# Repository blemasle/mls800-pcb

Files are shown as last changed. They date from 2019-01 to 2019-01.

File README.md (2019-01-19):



# MLS800 PCBs

MLS800 preview 1

The MLS800 is an open-source 1U rack unit MIDI controlled Loop Switcher with 8 audio loops.  

* 8 independent audio loops
* 128 presets
* Active preset is remotly controlled through MIDI `Program Change` messages
* Easy to read through a 4 digits 7 segments display and 9 illuminated switches

This repository contains KiCad files needed to produce the two PCBs.  

&nbsp;


See the [documentation](https://blemasle.github.io/mls800) for futher info on the project.

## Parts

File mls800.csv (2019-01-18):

References | Quantity | Manufacturer | Manufacturer PN
D2;D6 | 2 | Diodes Incorporated | S1A-13-F
CON1 | 1 | Switchcraft | RAPC722X
R14;R13 | 2 | Panasonic | ERJ-P06J220V
X1 | 1 | ECS Inc | ECS-160-20-5PX-TR
C1;C2 | 2 | Kemet | C0805C220K3GACTU
C6 | 1 | Kemet | C0805C105K3RACTU
F1 | 1 | Bourns | MF-MSMF050-2
C8 | 1 | Kemet | C1210C226K4RACTU
R4;R1;R6;R7 | 4 | Panasonic | ERJ-6GEYJ103V
C9;C5;C4;C7;C10;C11;C14;C18;C12;C20;C13 | 11 | Kemet | C0805C104M3RACTU
D1;D5 | 2 | Vishay | 1N4148W-E3-08
D3 | 1 | Kingbright | APT2012SYCK
R9;R10;R11;R12;R18;R8;R5 | 7 | Panasonic | ERJ-6GEYJ102V
D4 | 1 | Kingbright | APT2012EC
U3 | 1 | Microchip | 24LC256I/SN
R15;R17;R16 | 3 | Panasonic | ERJ-6GEYJ221V
IC1 | 1 | Fairchild Semiconductor | 6N137SM
C3;C17 | 2 | Kemet | C0805C224K3RACTU
P1;P4;P5 | 3 | FCI | 75869-131LF
VR2;VR1 | 2 | Bourns | CG0603MLC-05E
J1 | 1 | Molex Inc | 67068-8000
U1;U8 | 2 | Texas Instruments | LM340MP-5.0/NOPB
U2 | 1 | Atmel | ATMega32U4-AU
C15;C19;C16 | 3 | Panasonic | EEE-TPC101XAP
R2 | 1 | Panasonic | ERJ-6GEY0R00V
P2;P3 | 2 | TE Connectivity | 5212044-1
SW12 | 1 | Apem | MJTP1236C
U4 | 1 | Microchip | MCP23017-E/SS
RE1;RE2;RE3;RE4;RE5;RE6;RE7;RE8 | 8 | TE Connectivity | V23079E1201B301
J3;J4;J5;J6;J7;J8;J9;J10 | 8 | Neutrik | NSJ8HC
J2;J11 | 2 | Neutrik | NRJ4HF-1
U7;U6 | 2 | Texas Instruments | ULN2803ADW
AFF1 | 1 | Lite-On | LTC-5723HR
U5 | 1 | ams AG | AS1115-BSST
R19 | 1 | Panasonic | ERJ-6GEYJ243V
SW2;SW3;SW4;SW5;SW6;SW7;SW8;SW9;SW10;SW11 | 10 | Apem | 5GSH93582
SW2;SW3;SW4;SW5;SW6;SW7;SW8;SW9;SW10;SW11 | 10 | Apem | 1ES096

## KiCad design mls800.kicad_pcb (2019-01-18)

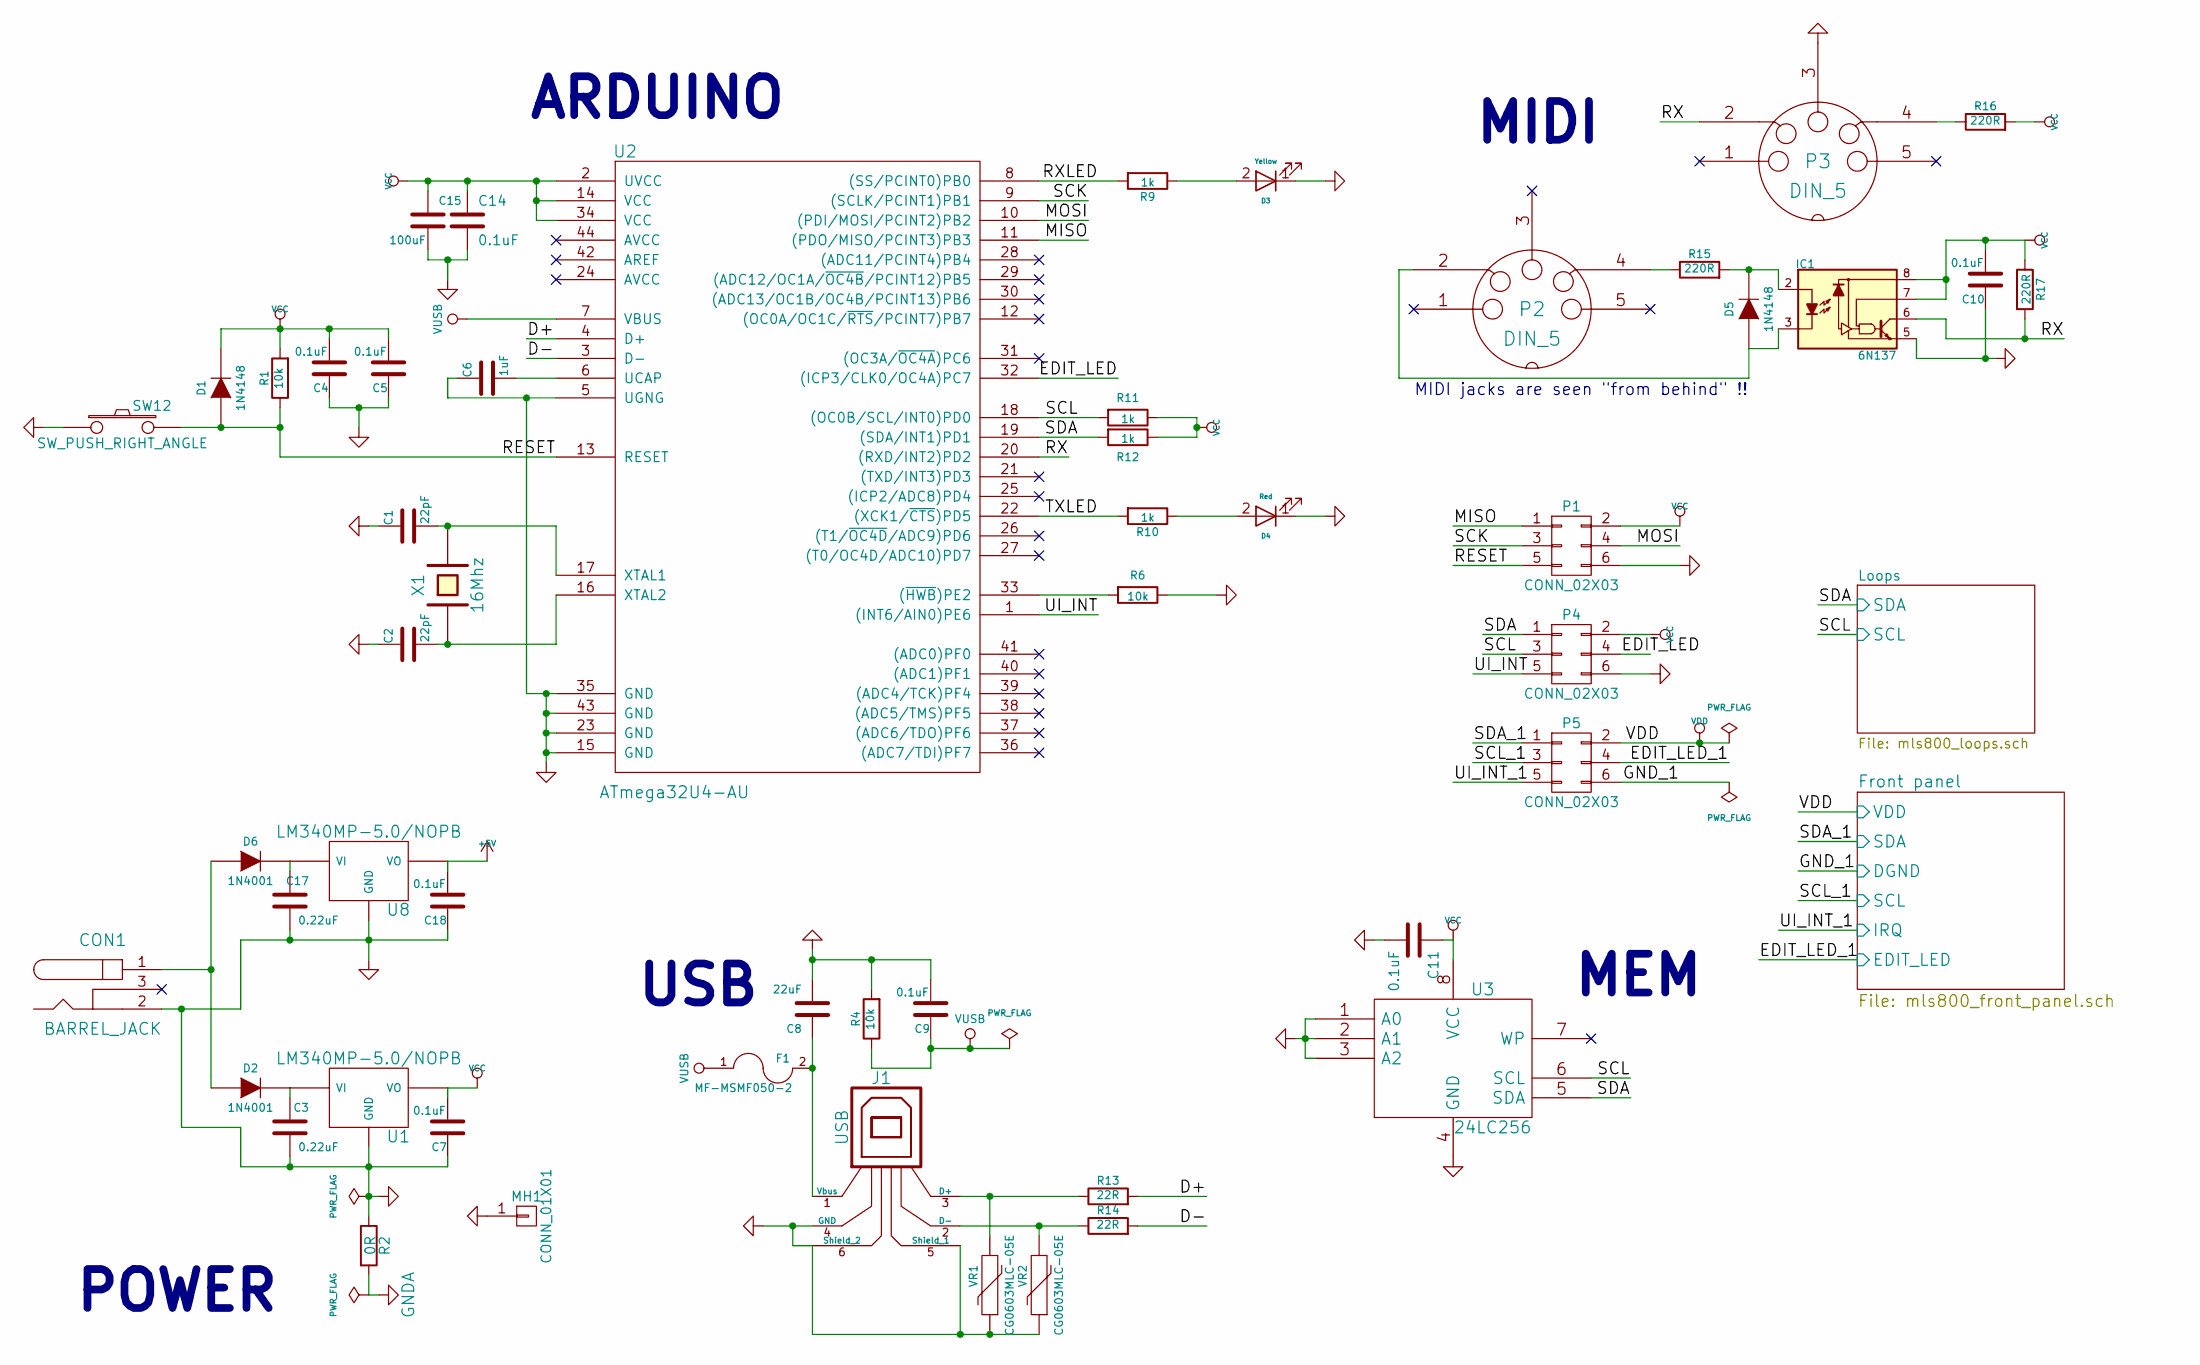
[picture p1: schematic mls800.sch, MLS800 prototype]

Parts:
C1, C2: 22pF; C_0805_HandSoldering; Manufacturer part number C0805C220K3GACTU
C3, C17: 0.22uF; C_0805_HandSoldering; Manufacturer part number C0805C224K3RACTU
C4, C5, C7, C9, C10, C11, C14, C18: 0.1uF; C_0805_HandSoldering; Manufacturer part number C0805C104M3RACTU
C6: 1uF; C_0805_HandSoldering; Manufacturer part number C0805C105K3RACTU
C8: 22uF; C_1210_HandSoldering; Manufacturer part number C1210C226K4RACTU
C15: 100uF; c_elec_6.3x7.7; Manufacturer part number EEE-TPC101XAP
CON1: BARREL_JACK; JACK_ALIM; Manufacturer part number RAPC722X
D1, D5: 1N4148; SOD-123_Handsoldering; Manufacturer part number 1N4148W-E3-08
D2, D6: 1N4001; Diode-SMA_Handsoldering; Manufacturer part number S1A-13-F
D3: Yellow; LED-0805; Manufacturer part number APT2012SYCK
D4: Red; LED-0805; Manufacturer part number APT2012EC
F1: MF-MSMF050-2; SMD-1812; Manufacturer part number MF-MSMF050-2
IC1: 6N137; DIP-8_SMD; Manufacturer part number 6N137SM
J1: USB; USB_B; Manufacturer part number 67068-8000
MH1: CONN_01X01; 1pin
P1, P4, P5: CONN_02X03; VASCH3x2; Manufacturer part number 75869-131LF
P2, P3: DIN_5; Manufacturer part number 5212044-1
R1, R4, R6: 10k; R_0805_HandSoldering; Manufacturer part number ERJ-6GEYJ103V
R2: 0R; R_0805_HandSoldering; Manufacturer part number ERJ-6GEY0R00V
R9, R10, R11, R12: 1k; R_0805_HandSoldering; Manufacturer part number ERJ-6GEYJ102V
R13, R14: 22R; R_0805_HandSoldering; Manufacturer part number ERJ-P06J220V
R15, R16, R17: 220R; R_0805_HandSoldering; Manufacturer part number ERJ-6GEYJ221V
SW12: SW_PUSH_RIGHT_ANGLE; Manufacturer part number MJTP1236
U1, U8: LM340MP-5.0/NOPB; SOT-223; Manufacturer part number LM340MP-5.0/NOPB
U2: ATmega32U4-AU; TQFP-44_10x10mm_Pitch0.8mm; Manufacturer part number ATMega32U4-AU
U3: 24LC256; SOIC-8_3.9x4.9mm_Pitch1.27mm; Manufacturer part number 24LC256I/SN
VR1, VR2: CG0603MLC-05E; R_0603_HandSoldering; Manufacturer part number CG0603MLC-05E
X1: 16Mhz; Q_49U3HMS; Manufacturer part number ECS-160-20-5PX-TR

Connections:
+5V: C18.2, U8.3 (VO); also elsewhere on the board
/D+: R13.2, U2.4 (D+)
/D-: R14.2, U2.3 (D-)
/EDIT_LED: P4.4, U2.32 ((ICP3/CLK0/OC4A)PC7)
/EDIT_LED_1: P5.4; also elsewhere on the board
/GND_1: P5.6; also elsewhere on the board
/MISO: P1.1, U2.11 ((PDO/MISO/PCINT3)PB3)
/MOSI: P1.4, U2.10 ((PDI/MOSI/PCINT2)PB2)
/RESET: D1.1 (A), P1.5, R1.1, SW12.2, U2.13 (RESET)
/RX: IC1.6, P3.2, R17.2, U2.20 ((RXD/INT2)PD2)
/RXLED: R9.2, U2.8 ((SS/PCINT0)PB0)
/SCK: P1.3, U2.9 ((SCLK/PCINT1)PB1)
/SCL: P4.3, R12.2, U2.18 ((OC0B/SCL/INT0)PD0), U3.6 (SCL); also elsewhere on the board
/SCL_1: P5.3; also elsewhere on the board
/SDA: P4.1, R11.2, U2.19 ((SDA/INT1)PD1), U3.5 (SDA); also elsewhere on the board
/SDA_1: P5.1; also elsewhere on the board
/TXLED: R10.2, U2.22 ((XCK1/~CTS~)PD5)
/UI_INT: P4.5, U2.1 ((INT6/AIN0)PE6)
/UI_INT_1: P5.5; also elsewhere on the board
GND: C1.1, C2.1, C3.1, C4.1, C5.1, C6.1, C7.1, C8.2, C9.2, C10.1, C11.2, C14.2, C15.2, C17.1, C18.1, CON1.2, D3.1 (K), D4.1 (K), IC1.5, J1.4 (GND), J1.5 (Shield_1), J1.6 (Shield_2), MH1.1, P1.6, P2.6 (GND), P2.7 (GND), P3.3, P3.6 (GND), P3.7 (GND), P4.6, R2.1, R4.2, R6.1, SW12.1, SW12.3 (GND), SW12.4 (GND), U1.2 (GND), U1.4 (GND), U2.5 (UGNG), U2.15 (GND), U2.23 (GND), U2.35 (GND), U2.43 (GND), U3.1 (A0), U3.2 (A1), U3.3 (A2), U3.4 (GND), U8.2 (GND), U8.4 (GND), VR1.1, VR2.1; also elsewhere on the board
GNDA: R2.2; also elsewhere on the board
unnamed: C1.2, U2.17 (XTAL1), X1.2
unnamed: C2.2, U2.16 (XTAL2), X1.1
unnamed: C3.2, D2.2 (K), U1.1 (VI)
unnamed: C6.2, U2.6 (UCAP)
unnamed: C8.1, F1.2, J1.1 (Vbus)
unnamed: C17.2, D6.2 (K), U8.1 (VI)
unnamed: CON1.1, D2.1 (A), D6.1 (A)
unnamed: D3.2 (A), R9.1
unnamed: D4.2 (A), R10.1
unnamed: D5.1 (A), IC1.3, P2.2
unnamed: D5.2 (K), IC1.2, R15.2
unnamed: J1.2 (D-), R14.1, VR2.2
unnamed: J1.3 (D+), R13.1, VR1.2
unnamed: P2.4, R15.1
unnamed: P3.4, R16.1
unnamed: R6.2, U2.33 ((~HWB~)PE2)
VCC: C4.2, C5.2, C7.2, C10.2, C11.1, C14.1, C15.1, D1.2 (K), IC1.7, IC1.8, P1.2, P4.2, R1.2, R11.1, R12.1, R16.2, R17.1, U1.3 (VO), U2.2 (UVCC), U2.14 (VCC), U2.34 (VCC), U3.8 (VCC); also elsewhere on the board
VCOM: C9.1, F1.1, R4.1, U2.7 (VBUS)
VDD: P5.2; also elsewhere on the board

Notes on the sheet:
POWER
USB
ARDUINO
MEM
MIDI
MIDI jacks are seen "from behind" !!

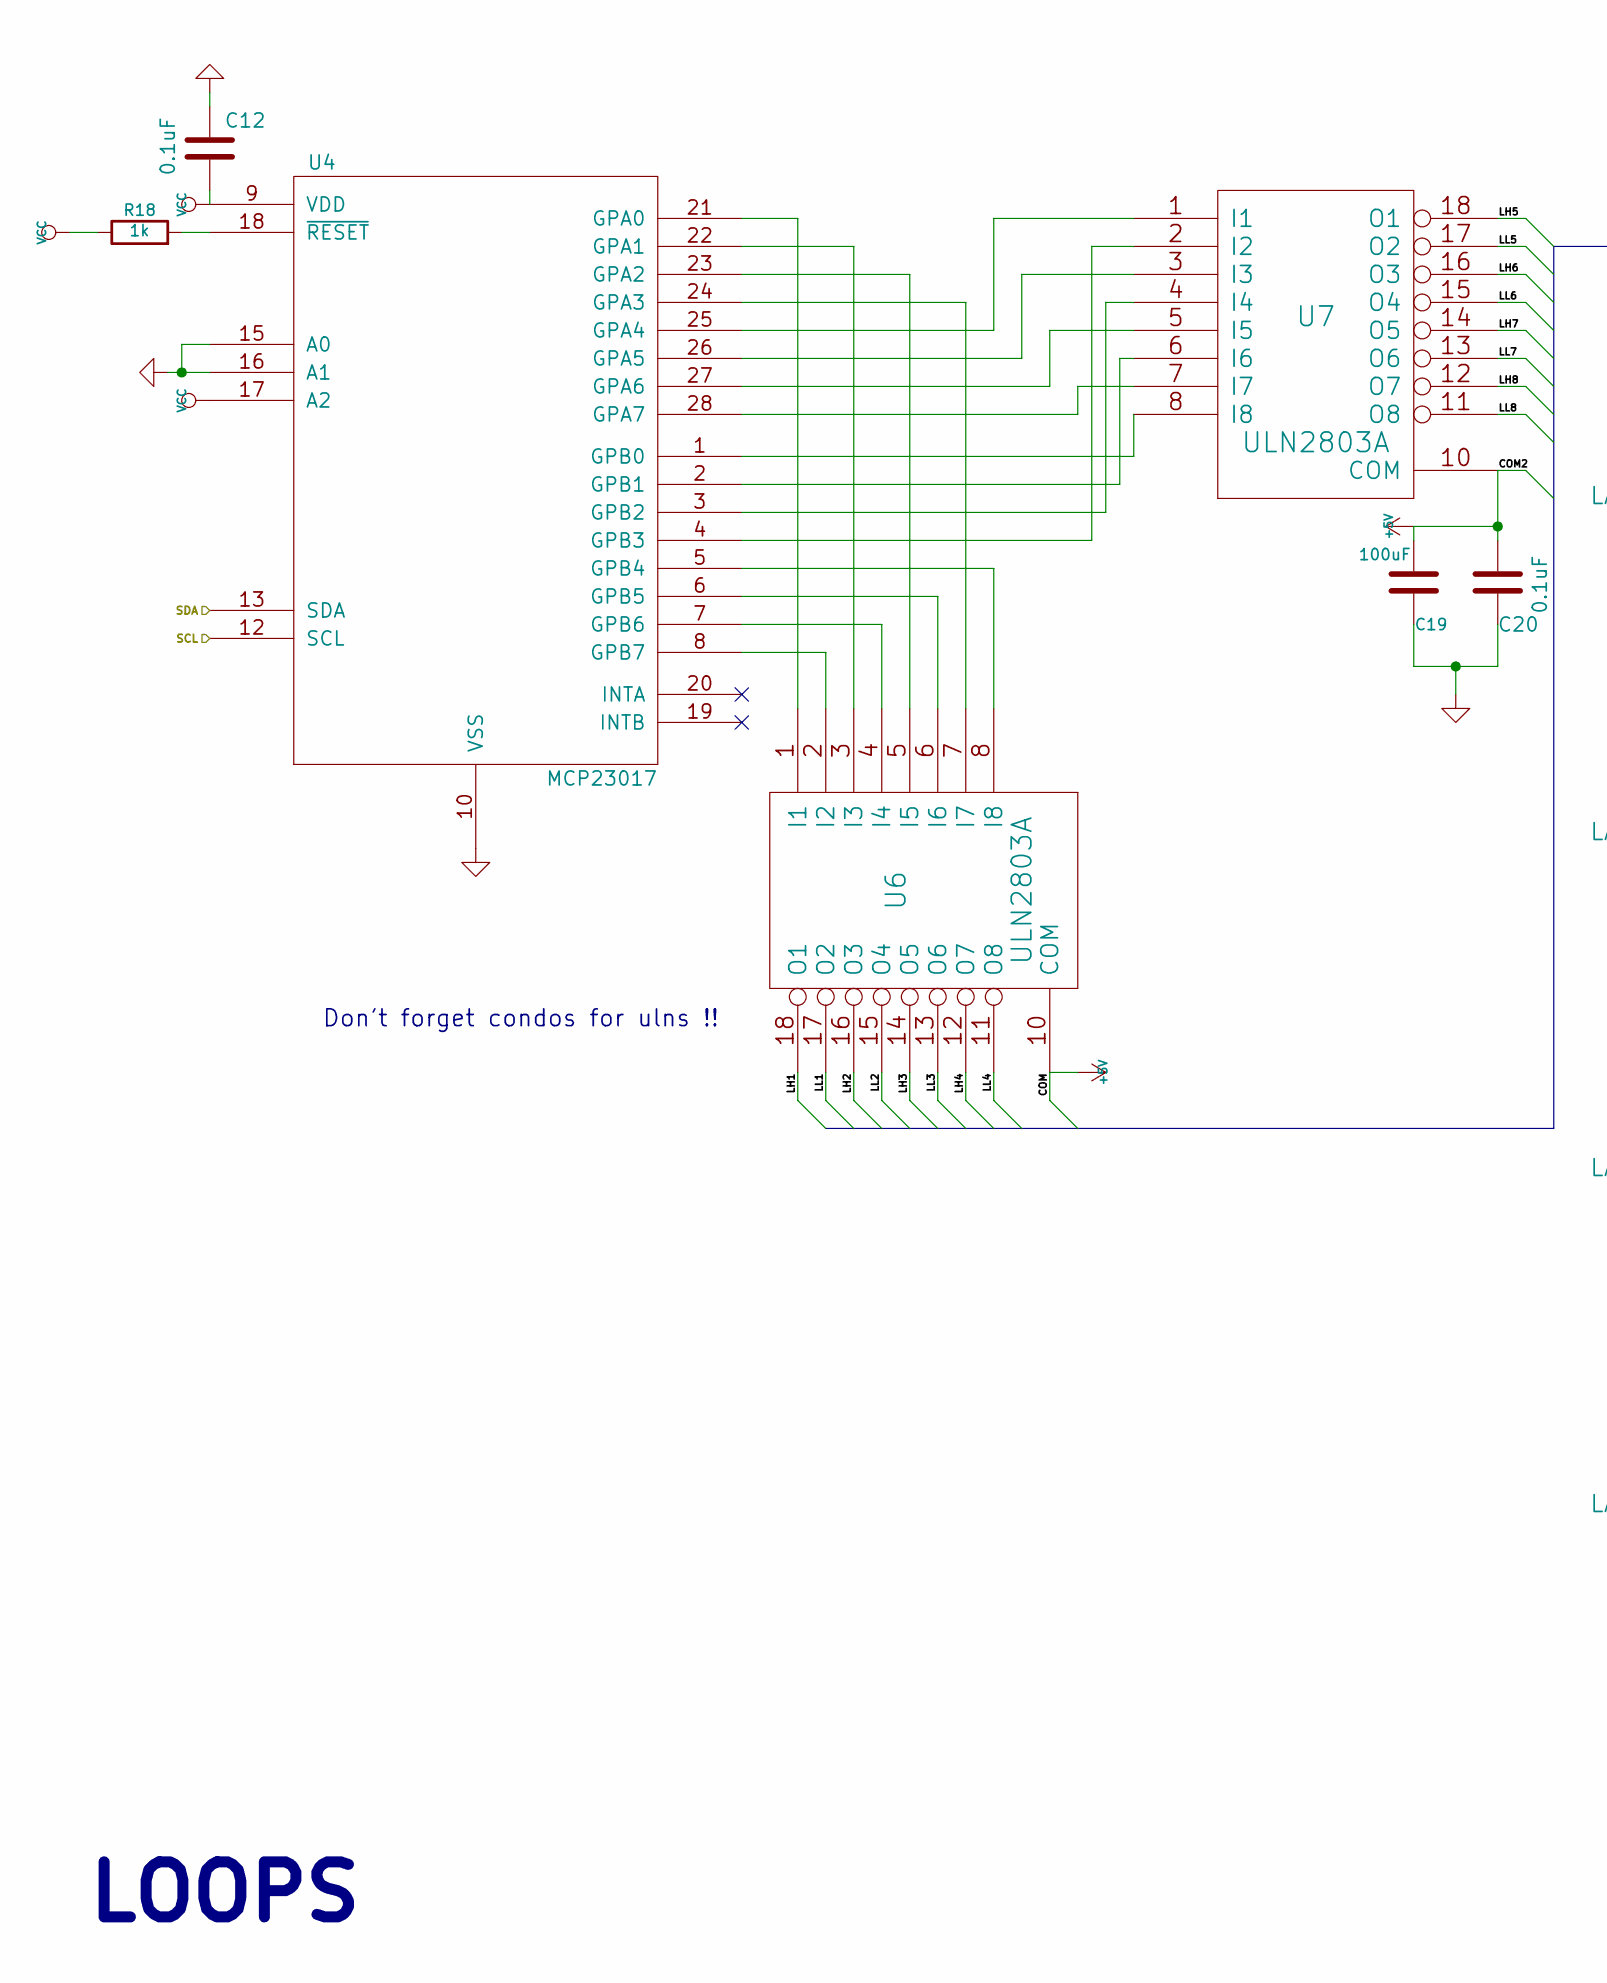
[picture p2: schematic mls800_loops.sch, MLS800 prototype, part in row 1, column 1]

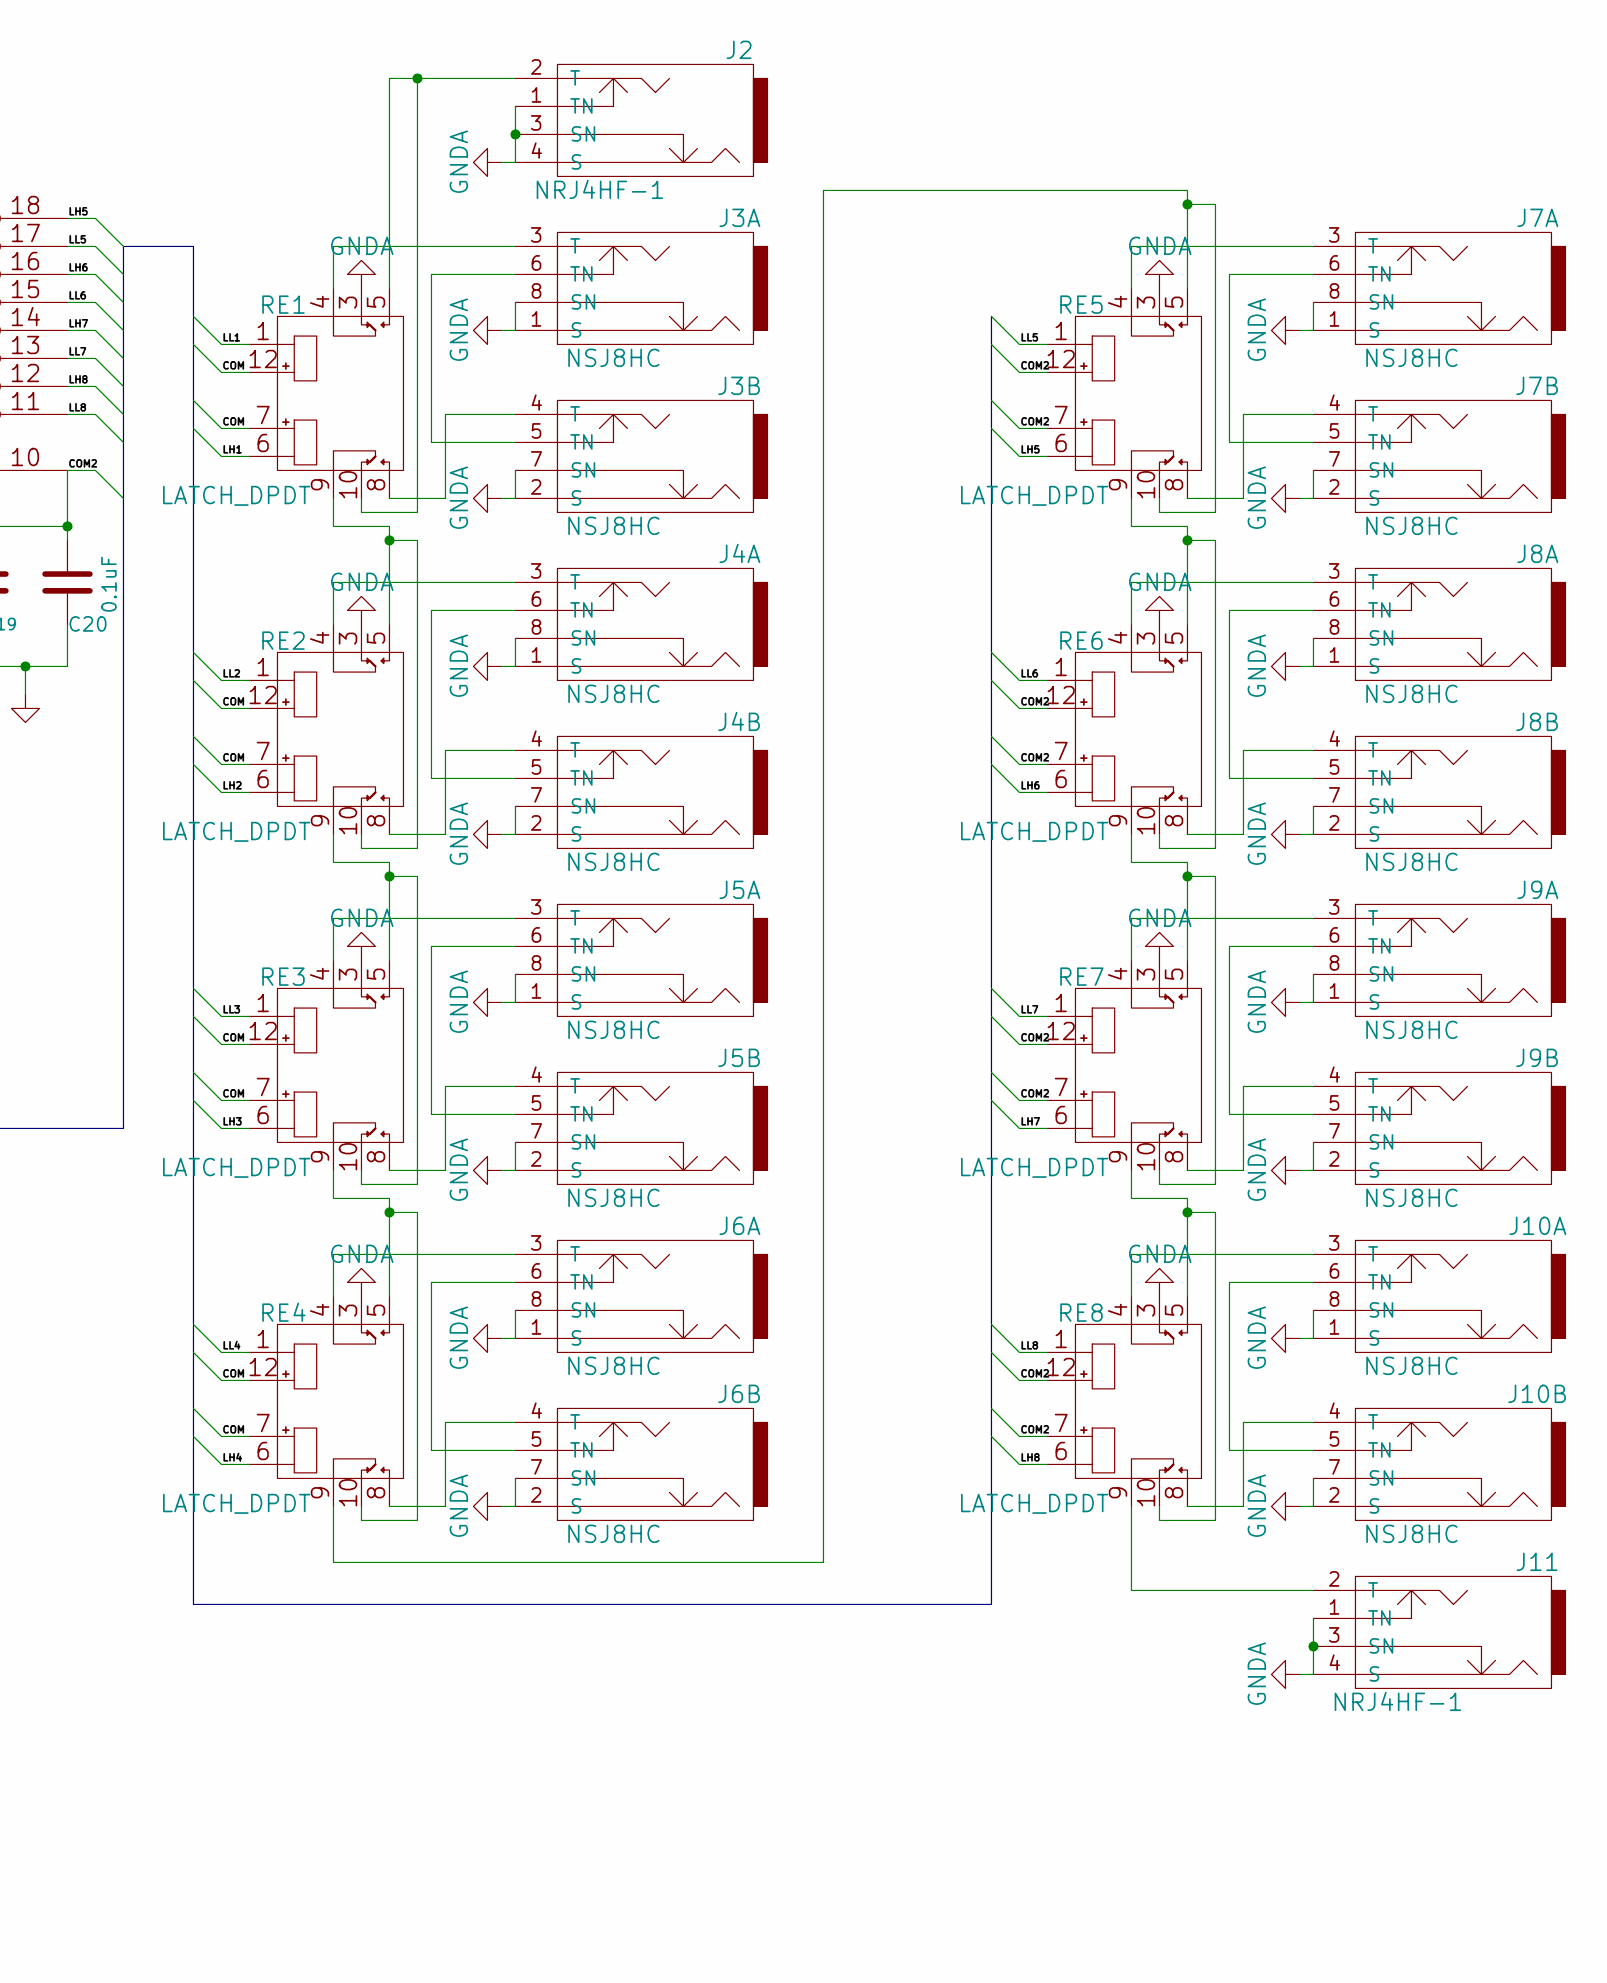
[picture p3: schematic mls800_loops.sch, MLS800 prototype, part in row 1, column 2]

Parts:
C12, C20: 0.1uF; C_0805_HandSoldering; Manufacturer part number C0805C104M3RACTU
C19: 100uF; c_elec_6.3x7.7; Manufacturer part number EEE-TPC101XAP
J2, J11: NRJ4HF-1; Manufacturer part number NRJ4HF-1
J3, J4, J5, J6, J7, J8, J9, J10: NSJ8HC; NSJ8HL; Manufacturer part number NSJ8HC
R18: 1k; R_0805_HandSoldering; Manufacturer part number ERJ-6GEYJ102V
RE1, RE2, RE3, RE4, RE5, RE6, RE7, RE8: LATCH_DPDT; Relay_SMD_DPDT-RT2_bistabil; Manufacturer part number V23079E1201B301
U4: MCP23017; SSOP-28_5.3x10.2mm_Pitch0.65mm; Manufacturer part number MCP23017-E/SS
U6, U7: ULN2803A; SOIC-18_7.5x11.6mm_Pitch1.27mm; Manufacturer part number ULN2803ADW

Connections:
+5V: C19.1, C20.2, RE1.7, RE1.12, RE2.7, RE2.12, RE3.7, RE3.12, RE4.7, RE4.12, RE5.7, RE5.12, RE6.7, RE6.12, RE7.7, RE7.12, RE8.7, RE8.12, U6.10 (COM), U7.10 (COM); also elsewhere on the board
/Loops/LH1: RE1.6, U6.18 (O1)
/Loops/LH2: RE2.6, U6.16 (O3)
/Loops/LH3: RE3.6, U6.14 (O5)
/Loops/LH4: RE4.6, U6.12 (O7)
/Loops/LH5: RE5.6, U7.18 (O1)
/Loops/LH6: RE6.6, U7.16 (O3)
/Loops/LH7: RE7.6, U7.14 (O5)
/Loops/LH8: RE8.6, U7.12 (O7)
/Loops/LL1: RE1.1, U6.17 (O2)
/Loops/LL2: RE2.1, U6.15 (O4)
/Loops/LL3: RE3.1, U6.13 (O6)
/Loops/LL4: RE4.1, U6.11 (O8)
/Loops/LL5: RE5.1, U7.17 (O2)
/Loops/LL6: RE6.1, U7.15 (O4)
/Loops/LL7: RE7.1, U7.13 (O6)
/Loops/LL8: RE8.1, U7.11 (O8)
/SCL: U4.12 (SCL); also elsewhere on the board
/SDA: U4.13 (SDA); also elsewhere on the board
GND: C12.1, C19.2, C20.1, U4.10 (VSS), U4.15 (A0), U4.16 (A1), U6.9 (GND), U7.9 (GND); also elsewhere on the board
GNDA: J2.1 (TN), J2.3 (SN), J2.4 (S), J3.1 (S), J3.2 (S), J3.7 (SN), J3.8 (SN), J3.9 (GNDA), J4.1 (S), J4.2 (S), J4.7 (SN), J4.8 (SN), J4.9 (GNDA), J5.1 (S), J5.2 (S), J5.7 (SN), J5.8 (SN), J5.9 (GNDA), J6.1 (S), J6.2 (S), J6.7 (SN), J6.8 (SN), J6.9 (GNDA), J7.1 (S), J7.2 (S), J7.7 (SN), J7.8 (SN), J7.9 (GNDA), J8.1 (S), J8.2 (S), J8.7 (SN), J8.8 (SN), J8.9 (GNDA), J9.1 (S), J9.2 (S), J9.7 (SN), J9.8 (SN), J9.9 (GNDA), J10.1 (S), J10.2 (S), J10.7 (SN), J10.8 (SN), J10.9 (GNDA), J11.1 (TN), J11.3 (SN), J11.4 (S), RE1.3, RE2.3, RE3.3, RE4.3, RE5.3, RE6.3, RE7.3, RE8.3; also elsewhere on the board
unnamed: J2.2 (T), RE1.5, RE1.10
unnamed: J3.3 (T), RE1.4
unnamed: J3.4 (T), RE1.8
unnamed: J3.5 (TN), J3.6 (TN)
unnamed: J4.3 (T), RE2.4
unnamed: J4.4 (T), RE2.8
unnamed: J4.5 (TN), J4.6 (TN)
unnamed: J5.3 (T), RE3.4
unnamed: J5.4 (T), RE3.8
unnamed: J5.5 (TN), J5.6 (TN)
unnamed: J6.3 (T), RE4.4
unnamed: J6.4 (T), RE4.8
unnamed: J6.5 (TN), J6.6 (TN)
unnamed: J7.3 (T), RE5.4
unnamed: J7.4 (T), RE5.8
unnamed: J7.5 (TN), J7.6 (TN)
unnamed: J8.3 (T), RE6.4
unnamed: J8.4 (T), RE6.8
unnamed: J8.5 (TN), J8.6 (TN)
unnamed: J9.3 (T), RE7.4
unnamed: J9.4 (T), RE7.8
unnamed: J9.5 (TN), J9.6 (TN)
unnamed: J10.3 (T), RE8.4
unnamed: J10.4 (T), RE8.8
unnamed: J10.5 (TN), J10.6 (TN)
unnamed: J11.2 (T), RE8.9
unnamed: R18.2, U4.18 (~RESET)
unnamed: RE1.9, RE2.5, RE2.10
unnamed: RE2.9, RE3.5, RE3.10
unnamed: RE3.9, RE4.5, RE4.10
unnamed: RE4.9, RE5.5, RE5.10
unnamed: RE5.9, RE6.5, RE6.10
unnamed: RE6.9, RE7.5, RE7.10
unnamed: RE7.9, RE8.5, RE8.10
unnamed: U4.1 (GPB0), U7.8 (I8)
unnamed: U4.2 (GPB1), U7.6 (I6)
unnamed: U4.3 (GPB2), U7.4 (I4)
unnamed: U4.4 (GPB3), U7.2 (I2)
unnamed: U4.5 (GPB4), U6.8 (I8)
unnamed: U4.6 (GPB5), U6.6 (I6)
unnamed: U4.7 (GPB6), U6.4 (I4)
unnamed: U4.8 (GPB7), U6.2 (I2)
unnamed: U4.21 (GPA0), U6.1 (I1)
unnamed: U4.22 (GPA1), U6.3 (I3)
unnamed: U4.23 (GPA2), U6.5 (I5)
unnamed: U4.24 (GPA3), U6.7 (I7)
unnamed: U4.25 (GPA4), U7.1 (I1)
unnamed: U4.26 (GPA5), U7.3 (I3)
unnamed: U4.27 (GPA6), U7.5 (I5)
unnamed: U4.28 (GPA7), U7.7 (I7)
VCC: C12.2, R18.1, U4.9 (VDD), U4.17 (A2); also elsewhere on the board

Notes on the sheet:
LOOPS
Don't forget condos for ulns !!

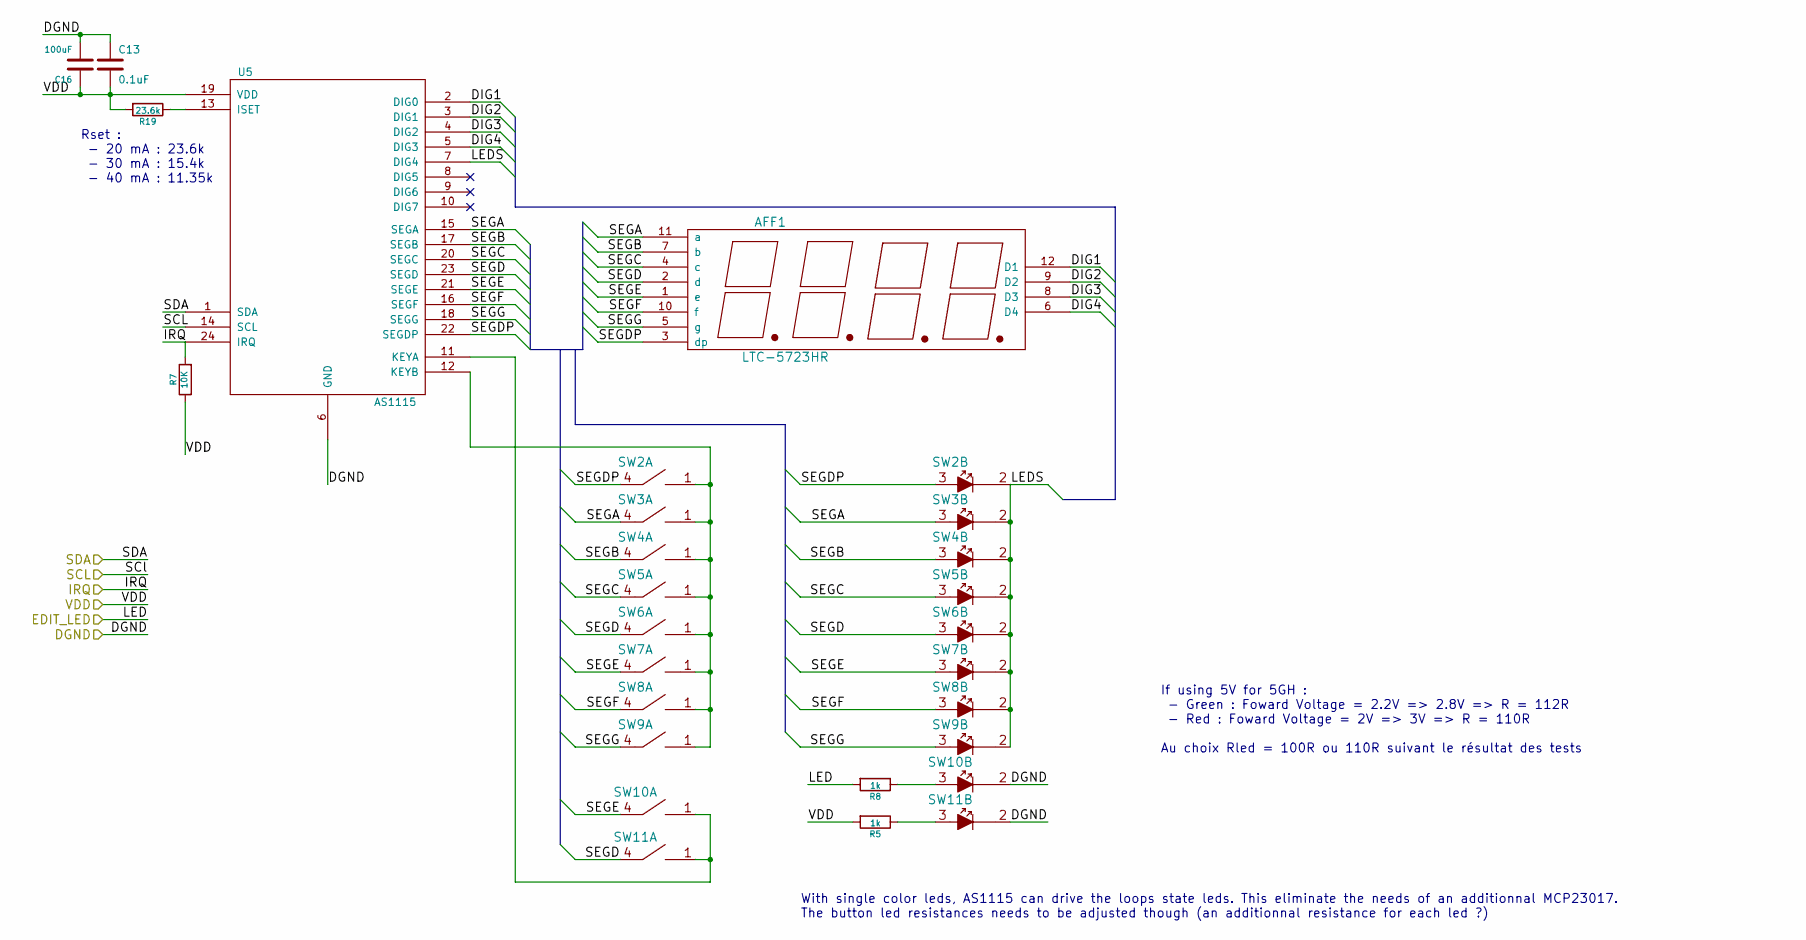
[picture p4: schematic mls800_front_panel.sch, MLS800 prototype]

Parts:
AFF1: LTC-5723HR; LTC-5723; Manufacturer part number LTC-5723HR
C13: 0.1uF; C_0805_HandSoldering; Manufacturer part number C0805C104M3RACTU
C16: 100uF; c_elec_6.3x7.7; Manufacturer part number EEE-TPC101XAP
R5, R8: 1k; R_0805_HandSoldering; Manufacturer part number ERJ-6GEYJ102V
R7: 10K; R_0805_HandSoldering; Manufacturer part number ERJ-6GEYJ103V
R19: 23.6k; R_0805_HandSoldering; Manufacturer part number ERJ-6GEYJ243V
SW2, SW3, SW4, SW5, SW6, SW7, SW8, SW9, SW10, SW11: SW_TACT_LED; MEC-5G; Manufacturer part number 5GSH93582
U5: AS1115; SSOP-24_3.9x8.7mm_Pitch0.635mm; Manufacturer part number AS1115-BSST

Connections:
/EDIT_LED_1: R8.2; also elsewhere on the board
/Front panel/DIG1: AFF1.12 (D1), U5.2 (DIG0)
/Front panel/DIG2: AFF1.9 (D2), U5.3 (DIG1)
/Front panel/DIG3: AFF1.8 (D3), U5.4 (DIG2)
/Front panel/DIG4: AFF1.6 (D4), U5.5 (DIG3)
/Front panel/LEDS: SW2.2, SW3.2, SW4.2, SW5.2, SW6.2, SW7.2, SW8.2, SW9.2, U5.7 (DIG4)
/Front panel/SEGA: AFF1.11 (a), SW3.3, SW3.4, U5.15 (SEGA)
/Front panel/SEGB: AFF1.7 (b), SW4.3, SW4.4, U5.17 (SEGB)
/Front panel/SEGC: AFF1.4 (c), SW5.3, SW5.4, U5.20 (SEGC)
/Front panel/SEGD: AFF1.2 (d), SW6.3, SW6.4, SW11.4, U5.23 (SEGD)
/Front panel/SEGDP: AFF1.3 (dp), SW2.3, SW2.4, U5.22 (SEGDP)
/Front panel/SEGE: AFF1.1 (e), SW7.3, SW7.4, SW10.4, U5.21 (SEGE)
/Front panel/SEGF: AFF1.10 (f), SW8.3, SW8.4, U5.16 (SEGF)
/Front panel/SEGG: AFF1.5 (g), SW9.3, SW9.4, U5.18 (SEGG)
/GND_1: C13.1, C16.2, SW10.2, SW11.2, U5.6 (GND); also elsewhere on the board
/SCL_1: U5.14 (SCL); also elsewhere on the board
/SDA_1: U5.1 (SDA); also elsewhere on the board
/UI_INT_1: R7.2, U5.24 (IRQ); also elsewhere on the board
unnamed: R5.1, SW11.3
unnamed: R8.1, SW10.3
unnamed: R19.1, U5.13 (ISET)
unnamed: SW2.1, SW3.1, SW4.1, SW5.1, SW6.1, SW7.1, SW8.1, SW9.1, U5.12 (KEYB)
unnamed: SW10.1, SW11.1, U5.11 (KEYA)
VDD: C13.2, C16.1, R5.2, R7.1, R19.2, U5.19 (VDD); also elsewhere on the board

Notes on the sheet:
Rset : - 20 mA : 23.6k - 30 mA : 15.4k - 40 mA : 11.35k
With single color leds, AS1115 can drive the loops state leds. This eliminate the needs of an additionnal MCP23017. The button led resistances needs to be adjusted though (an additionnal resistance for each led ?)
If using 5V for 5GH : - Green : Foward Voltage = 2.2V => 2.8V => R = 112R - Red : Foward Voltage = 2V => 3V => R = 110R Au choix Rled = 100R ou 110R suivant le résultat des tests

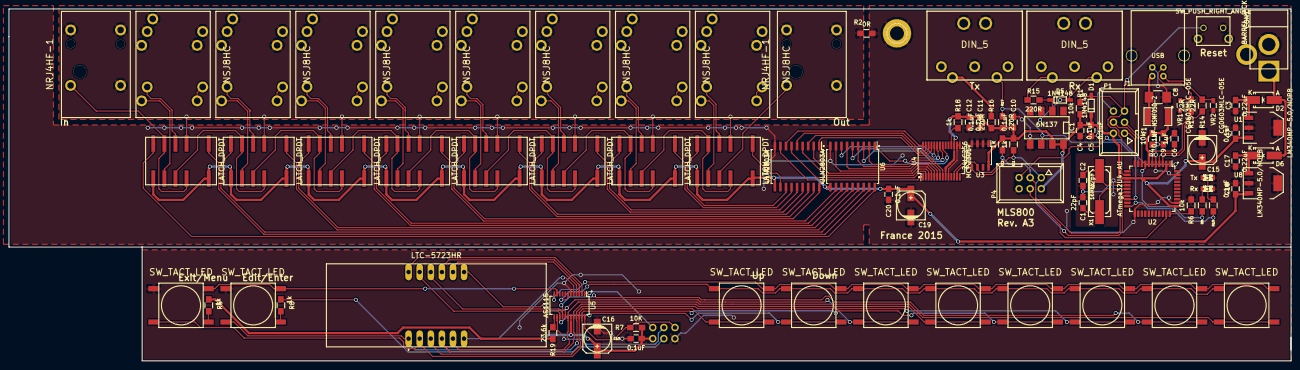
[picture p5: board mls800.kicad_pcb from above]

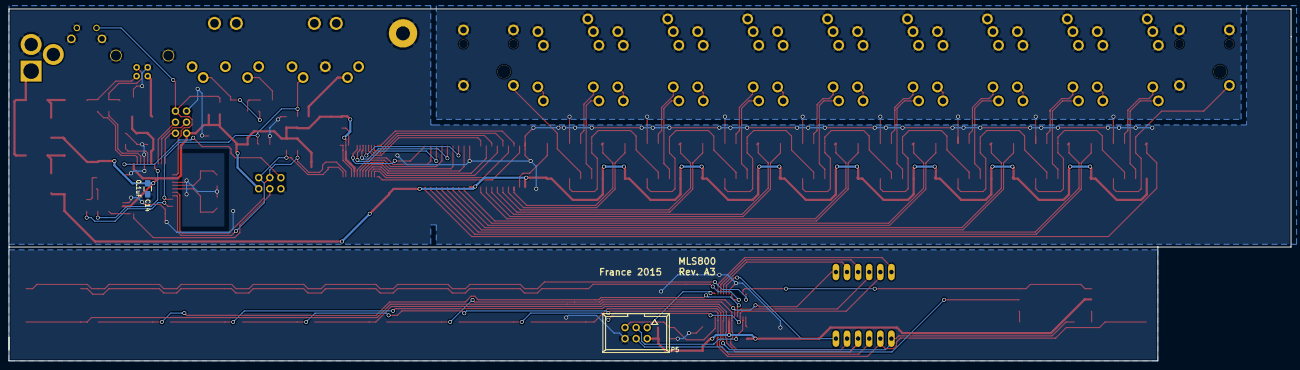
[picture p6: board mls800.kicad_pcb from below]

Board: 2 copper layers, 293.4 x 80.5 mm, 95 parts (2 on the bottom side), 124 nets.

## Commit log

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2014-06-23 MLS800 * Lots of change in diagram/schematic * Added external parts
    [mls800.sch, mls800_display.sch, mls800_loops.sch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]
2014-06-23 MLS800 * Fixed missing non connected symbols
    [mls800.sch, mls800_display.sch, mls800_loops.sch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]
2014-06-24 MLS800 * Fixed some crc errors * Fixed wrong AREF/UCAP schematics * Generated netlist
    [mls800.sch, mls800_display.sch, mls800_loops.sch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]
2014-08-17 MLS800 * Added separated GND : AGND & GND * Revamped the loops schema * Put values on all components * Started to add footprint annotations to some resistors
    [mls800.sch, mls800_display.sch, mls800_loops.sch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]
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2014-10-15 MLS800 : added LTC-5723HR to custom-display library
    MLS800 : fixed AS1115 pin placement to match main grid
    [mls800.sch, mls800_display.sch, mls800_front_panel.sch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]
2014-10-15 MLS800 : fixed missing components
    [mls800.sch, mls800_display.sch, mls800_front_panel.sch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]
2014-10-15 MLS800 : fixed broken layout
    MLS800 : added some comments on schematics rather than using a notepad :)
    [mls800.sch, mls800_front_panel.sch, mls800_misc.sch]
2014-10-16 MLS800 : disabled switch tact led "interchangeable" units => fixed annotations
    MLS800 : front panel schematic seems to be completed
    [mls800.sch, mls800_display.sch, mls800_front_panel.sch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]
2014-10-16 MLS800 : disabled switch tact led "interchangeable" units => fixed annotations
    MLS800 : fixed some erc errors in old "misc" sheet
    [mls800.sch, mls800_display.sch, mls800_front_panel.sch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]
2014-10-16 MLS800 : removed useless power flag
    MLS800 : fixed most errors and warnings
    ATMEGA32U : fixed missing "power input" pins
    [mls800.sch, mls800_display.sch, mls800_front_panel.sch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]
2014-11-24 MLS800
    * updated layout to match AS1115 diagrams
    * added pull-up resistors
    * removed useless sheets
    [mls800.sch, mls800_display.sch, mls800_front_panel.sch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]
2014-11-25 MLS800
    * removed unnecessary filter on AVCC & AVCC1
    * removed AREF connection
    [mls800.sch, mls800_front_panel.sch, mls800_loops.sch]
2014-11-25 MLS800
    * removed note about AREF and AVCCs
    [mls800.sch]
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2014-12-02 MLS800
    * added two news footprints
    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
    [mls800.sch, mls800_front_panel.sch, mls800_loops.sch]
2014-12-04 MLS800
    * added two news footprints (bistable relay & simple neutrik jack)
    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
    [mls800.sch, mls800_front_panel.sch, mls800_loops.sch]
2014-12-07 MLS800
    * added footprint for double jack
    * footprints assignements
    [mls800_loops.sch]
2014-12-07 MLS800
    * fixed simple jack footprint
2014-12-08 MLS800
    * fixed bistable relay pinout
    * fixed lm340 pinout
    * fixed missing footprints from older kicad version
    [mls800.sch, mls800_front_panel.sch, mls800_loops.sch]
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2014-12-17 MLS800
    * routing
    * reversed LL side of the MCP23017 loops control for better layout (needs to be impacted on code side)
    [mls800.kicad_pcb, mls800_loops.sch]
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2014-12-21 MLS800
    * routing : reversed routing of the core pcb
    * footprint placement
    [mls800.kicad_pcb, mls800.sch]
2014-12-21 MLS800
    * routing : core pcb & components
    [mls800.kicad_pcb]
2014-12-22 MLS800
    * schematic : added pin header for board connectivity & moved some parts to the front panel layout
    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
    [mls800.kicad_pcb, mls800_front_panel.sch]
2015-01-02 MLS800
    * fixed jacks footprints
2015-01-05 MLS800
    * schematic : changed all 1n4148 to bournes references
    * changed footprints to match bournes ones
    * re routed all the loops part of the pcb
    [mls800.kicad_pcb, mls800.sch, mls800_loops.sch]
2015-01-05 MLS800
    * adapted filled zones to previous re routing of loops
    [mls800.kicad_pcb]
2015-01-15 MLS800
    * unsplit AGND and DGND
    * retouted relays
    * relayout of gnd zone
    [mls800.kicad_pcb, mls800.sch, mls800_loops.sch]
2015-01-16 MLS800
    * rerouting
    * changed pad clearance to avoid DRC errors on small footprints
    * set some 3d shapes
    [mls800.kicad_pcb]
2015-01-18 MLS800
    * copper zones
    * layout optimization
    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
    [mls800.kicad_pcb]
2015-01-19 MLS800
    * pcb size reduction
    * change u2 to internal kicad library (may induce error in layout, this commit comes just before applying netlist)
    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
    [mls800.kicad_pcb, mls800.sch, mls800_loops.sch]
2015-01-19 MLS800
    * changed AGND to GND in jack connectors
    * started front panel rerouting
    [mls800.kicad_pcb, mls800_loops.sch]
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2015-01-21 MLS800
    * solved some VCC supply issues
    [mls800.kicad_pcb]
2015-01-21 MLS800
    * fixed missing relay traces
    * fixed missing vcc traces
    [mls800.kicad_pcb]
2015-01-21 MLS800
    * done most of the routing of the front panel board
    [mls800.kicad_pcb]
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2015-01-22 MLS800
    * gnd zones
    * v-grooving
    * one pcb
    [mls800.kicad_pcb]
2015-01-25 MLS800
    * changed D2 footprint according to availability
    [mls800.kicad_pcb, mls800.sch]
2015-01-26 MLS800
    * started rerouting of the main board
    [mls800.kicad_pcb]
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2015-02-12 MLS800
    * rerouting of some part
    * added filter cap to each digital part
    * added board filter cap
    * set 3d shapes for remaining parts (missing custom parts)
    * added footprint for small pushbutton
    [mls800.kicad_pcb, mls800.sch, mls800_front_panel.sch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]
2015-02-12 MLS800
    * moved audio jacks to let some spaces for mounting holes
    * rerouted audio jacks
    [mls800.kicad_pcb]
2015-02-16 MLS800
    * mouting holes placement & clearance
    * choosed m3 accroding to http://www.eevblog.com/forum/eda/m3-screw-drill-diameter/
    [mls800.kicad_pcb]
2015-02-18 MLS800
    * mouting holes footprint
    * footprint reference placement
    [mls800.kicad_pcb]
2015-02-18 MLS800
    * copper zone clearance
    * round drilling holes
    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
    [mls800.kicad_pcb, mls800.sch, mls800_front_panel.sch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]
2015-02-22 MLS800
    * fixed MIDI capacitor being wired to RX rather than GND
    [mls800.kicad_pcb, mls800.sch]
2015-02-24 MLS800
    * added ULN2803A
    * relays schematics using 2 of the previous chip
    * added an analog ground for jacks
    [mls800.kicad_pcb, mls800.sch, mls800_front_panel.sch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]
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2015-02-25 Mixed up pins to made routing easier (needs to be reported on dev side though)
    Started re-routing relays again
    [mls800.kicad_pcb, mls800.sch, mls800_loops.sch]
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2015-03-01 Re routed ULN/relays to provide better PCB routing
    [mls800.kicad_pcb, mls800.sch, mls800_loops.sch]
2015-03-01 Re routed ULN/relays to provide better PCB routing : MCP to ULNS routing
    [mls800.kicad_pcb]
2015-03-01 Relay & Relay drivers alternate routing, saving a lot of space and vias
    [mls800.kicad_pcb]
2015-03-01 Added secondary 5V rails for ULN & relays on schematics & PCB
    Added power supply ripple protection capacitors for ULN
    [mls800.kicad_pcb, mls800.sch, mls800_loops.sch]
2015-03-01 Resize PCB
    Changed PCB form to stay into "2 panelized" form
    [mls800.kicad_pcb]
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2015-03-04 Minor PCB adjustements
    Fixed R7 tied to ground instead of VCC (needs to be reported on PCB)
    [mls800.kicad_pcb, mls800_front_panel.sch]
2015-03-04 Fixed R7 tied to ground instead of VCC on the PCB
    All relays grounds are now tied to GNDA
    [mls800.kicad_pcb, mls800_loops.sch]
2015-03-04 Fixed inverted relays wiring (COM is VDD, not GND)
    Regenerated netlist
    [mls800.sch, mls800_loops.sch]
2015-03-05 Fixed gnd planes
    [mls800.kicad_pcb]
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2015-03-07 Components fields assignments
    Rerouted relays (set/reset was wired the same way, to reset would have no effect)
    Set and reset port have been exchanged to facilitate routing (to be reported on firmware)
    Edited relay component
    [mls800.csv, mls800.kicad_pcb, mls800.sch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]
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2015-03-09 Ordered PCB (with one major mistake : the two 22R are two small to dissipate 3W !!)
    BOM filling
    [mls800.csv, mls800.kicad_pcb, mls800.sch]
2015-03-09 Changed reset caps to match other caps values (uF instead of nF)
    [mls800.sch]
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2015-03-11 Replace all condos with Kemet ones
    NO solution has been found for the wrong footprint about 100uF condos
    [mls800.sch, mls800_front_panel.sch, mls800_loops.sch]
2015-03-11 Regenerated BOM
    BOM match the ordered PCBs, with all the mistakes :/
    Tweaked csv BOM so it can be imported into Mouser
    Removed SDS-50J from the BOM as it won't match the footprint
    Added cable stripper parts to the csv BOM
    [mls800.csv, mls800_front_panel.sch]
2015-03-24 Fixed SEG_F cannot be used by a switch as AS1115 is in self addressing mode
    Fixed main switches order (DP was last instead of first)
    [mls800_front_panel.sch]
2015-03-24 Fixed silkscreen for up/down buttons
    [mls800.kicad_pcb]
2015-03-24 Fixed C8 begin a tantalum capacitor, replaced with a Kemet 0805 10% ceramic capacitor
    [mls800.sch]
2015-03-24 Fixed DIN_5 footprint pins not being aligned with schema part
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2015-03-25 Replaced 1n4148 diodes with standard SOD-123 packages from vishay
    [mls800.sch]
2015-03-25 Fixed DIN_5 footprint to something more generic (at least most commonly found)
    Created a new DIN_5 component with pin 6 & 7 tied to ground
    [mls800.sch]
2015-03-26 Fixed relays schematics by inverting pin 4,3 & 10,9
2015-03-26 Fixed 2x3 pin header footprint
    [mls800.sch]
2015-03-26 Regenerated netlist after fixes for PCB REV A2
2015-03-26 Imported new netlist
    Deleted wrong tracks
    Re arrange basic footprints
    [mls800.kicad_pcb, mls800.sch, mls800_loops.sch]
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2015-03-27 Added vertical push button component & footprint Updated pcb with that last footprint
    [mls800.kicad_pcb, mls800.sch]
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2015-03-27 Motherboard copper planes were off by a few centimeters Routing of data traces (sda, scl)
    [mls800.kicad_pcb]
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2015-03-27 Found an acceptable routing pattern Started audio jacks routing.
    [mls800.kicad_pcb]
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2015-03-30 Fixed buttons switches nets Regenerated netlist
    [mls800_front_panel.sch]
2015-03-30 Fixed front panel capacitor footprint
    [mls800.kicad_pcb, mls800.sch, mls800_front_panel.sch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]
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2015-03-30 Fixed wrong label name for SEGG button
    [mls800.kicad_pcb, mls800_front_panel.sch]
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2015-03-31 Optimized relays nets to allow copper planes to be filled
    [mls800.kicad_pcb]
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2015-04-05 Front panel routing
    Fixed motherboard copper plane on the right side of relays
    [mls800.kicad_pcb]
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2015-04-05 Fixed front panel ground plane between butons
    [mls800.kicad_pcb]
2015-04-06 Fixed DIN5 footprint pin order
    Fixed SOD-123_Handsoldering footprint
    Placed all components silkscreen
    [mls800.kicad_pcb, mls800.sch]
2015-04-06 Fixed front panel PCB outline
    Moved all button silkscreen to the north
    [mls800.kicad_pcb]
2015-04-06 Moved reset button silkscreen closer to the button itself
    [mls800.kicad_pcb]
2015-04-06 Fixed MIDI connectors gap to allow use of another part number if needed
    [mls800.kicad_pcb]
2015-04-06 Fixed sw11 & sw10 ref position
    [mls800.kicad_pcb]
2015-04-06 Fixed MIDI Rx power supply trace width
    [mls800.kicad_pcb]
2015-04-06 Fixed COM being marked as negative on relays
    [mls800.kicad_pcb]
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2015-04-06 Fixed some silkscreen positions
    [mls800.kicad_pcb]
2015-04-06 Made the MIDI data pin smaller to have a better fit
    [mls800.kicad_pcb]
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2015-04-07 Fixed some 3dshapes
    [mls800.kicad_pcb]
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2015-04-08 Imported netlist
    Rearranged USB data & power supply lines
    Added keepout area for Crystal/Atmel VCC & GND net isolation
    [mls800.kicad_pcb]
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2015-04-09 Inverted capacitors and crystal position Shifted crystal local ground plane to the left
    [mls800.kicad_pcb]
2015-04-09 Routing Silkscreen placement Moved crystal and caps to the south because of the P1 connector
    [mls800.kicad_pcb]
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2015-06-22 Fixed reversed MIDI jacks footprint
    [mls800.csv, mls800.kicad_pcb, mls800.sch]
2015-07-18 Fixed 6N137 Venabled disconnected
    [mls800.kicad_pcb, mls800.sch]
2015-07-18 Fixed jack pins inversions
    [mls800.kicad_pcb, mls800_loops.sch]
2015-07-19 Fixed jack pins inversions
    Changed front panel silkscreen text & position
    [mls800.kicad_pcb]
2015-07-19 Change SOD-123 footprint to include cathode annotation once printed
    Added a point marker to ATmega to include pin 1 annotation once printed
    [mls800.kicad_pcb]
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2015-07-19 Fixed deleted nest after merge
    [mls800.kicad_pcb]
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2019-01-18 Made all necessary changes for the sch to pcb workflow to work again with newest KiCad versions
    [mls800.kicad_pcb, mls800.sch, mls800_loops.sch]
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

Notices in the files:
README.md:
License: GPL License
